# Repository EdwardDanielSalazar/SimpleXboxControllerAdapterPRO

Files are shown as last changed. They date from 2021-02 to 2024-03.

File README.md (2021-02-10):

# Simple Xbox Controller Adapter

## Functionality

Following the instructions below and using the [latest release](https://github.com/jimnarey/SimpleXboxControllerAdapter/releases) of this project you can create a simple Arduino-based adapter to use Xbox 360, Xbox One, PS3 and PS4 controllers with an original Xbox console.

## Background

This is an adaptation/fork of Ryzee119's excellent [four-way wired/wireless controller adapter](https://github.com/Ryzee119/ogx360/) to allow the use of Xbox One and Xbox 360 controllers (wired and wireless) on an original Xbox console. 

The objectives of this project were:
* A simple hardware build, using only off-the-shelf parts (at present, an Arduino Leonardo paired with a generic USB Host Shield). 
* Simple soldering. *A no solder version is possible if using the right choice of USB Host Shield*. 
* Reduced, simpler code to make playing around with it as straightforward as possible.
* Reduced functionality, reflecting the simpler code. Only wired controllers are supported and Steel Battalion emulation is not. 
* Support for additional controllers (so far, PS3 & PS4 controller support has been added).
* To provide full, foolproof instructions to enable anyone who's broadly comfortable with an Arduino to make an adapter and anyone who is broadly comfortable with the command line and IDEs to edit and build the code. So this document is a key part of the project.

This started when I dusted off my old Xbox and wanted to make something to use newer controllers with it. There's plenty of previous work on this and as I develop this document I'll link to more and more of it, but even with some experience of AVR and PIC programming it was a bit of a slog working out how to do it. The two biggest barriers were the complexity of some of the projects out there and/or getting them to build using reliable, free/open-source tools.

A significant factor in basing this project on ogx360 rather than XBOXPadMicro/XInput (see below) was that it was possible to clone, edit, and build without too much fighting with tools/IDE(s). The ogx360 project was originally built in Atmel/Microchip Studio which is Windows only (I could have lived with this) but it kept causing my mouse pointer to stall every 60 seconds (I really couldn't) because it apparently [fears some USB mice](https://www.avrfreaks.net/forum/mouse-pointer-stutters-when-connecting-usb-devices-while-running). This project started out with VSCode.

Even better, ogx360 has been transitioned to Platform IO and this project has followed suit. The old VSCode/CMake tools branch can be found at cmake_master and was used up to release 1.2.

Another important factor was starting with something which included the Xbox console's vendor-specific challenge/response values (see 'Alternatives & other projects to look at' below for more on this).

### Status

Release 1.3 differs from ogx360 as follows:
* Support for Xbox One and Xbox 360 *wireless* controllers has been removed.
* Support for multiple controllers has been removed. It supports a single controller connected via USB.
* Steel Battalion support has been removed, resulting in a smaller binary (and space for more controllers to be supported).
* PS3 controller support (via USB) has been added. 
* PS4 controller support (via USB) has been added. 
* Basic motion controls, using PS3/4 controllers is implemented.
* Motion controls can be enabled/disabled (PS + R2)
* Motion control sensitivity can be set (PS + R1) - crude, and definitely beta.
* The code supports an OLED screen displaying rumble/motion status.
* Replacement STL files for 3D printing a case have been added. For now, these assume use of an OLED screen. A non-OLED case to follow.
* The non-OLED release isn't properly tested. Consider beta for now.

### Future Work

These are broadly the priorities for now, not necessarily in order:
* Add instructions for building with an Arduino Pro Micro and mini USB Host Shield. This won't be a no-solder option but will be more compact. Thanks to Phantom8 for some really useful help with this already.
* Improving this document. The current build instructions rely on using VS Code (a command line only option will follow) and don't fully cover MacOS or cover Windows at all.
* Adding some scripts to make flashing the binary easier.

The OLED version currently uses 98% of the Leonardo's flash so it won't be possible to add further controllers without removing something else. Since removing the OLED only frees up about 9% of the flash, changes to the code will probably be limited to bug fixes and minor improvements, e.g. to the motion sensitivity options. I'm beginning to look at other microcontrollers to provide for significant additional functionality.

## Making One

For now, these instructions cover using a 'full size' Arduino Leonardo and USB Host Shield. You could get it working with an Arduino Micro, Pro Micro (set to run on 5V at 16Mhz) with a little adaptation and I'll add instructions for this in due course. Using a Leonardo is the simplest way, however.

### You will need

* An Arduino Leonardo/clone. Make sure it has the ICSP pin header (the separate, 6 pin header in the rear/centre). All those I could see on a quick skim of Amazon and eBay seemed to have one but I've seen references online to clones which do not.

Arduino Leonardo with ICSP header highlighted

* A standard size USB Host Shield (i.e. not one designed for a Pro Micro/Mini). Again, make sure this has the ICSP socket/header on the underside:

Underside of host shield with ICSP header/plug

* If you'd prefer to avoid soldering altogether, also ensure your choice of shield comes with the power supply pads pre-soldered. Mine, made by ARCELI, did not but it's the work of minutes if you're comfortable with soldering iron. Amazon (in the UK, at least) has an unbranded alternative (for about twice the price!) with the pads pre-soldered. These are the three pads:

Arduino USB host shield with power supply pads highlighted

* A USB-A female to Xbox Controller male/plug adapter. These are a few £/$ on eBay and [a better choice than hacking apart an Xbox peripheral](https://xboxdevwiki.net/Xbox_Input_Devices#USB_Adapters)
* A total of two micro USB cables. Most Leonardos come with one.

## For the OLED Version

* One SSD1306-based 128x32 OLED screen. These are available cheaply on Amazon or eBay.
* Four wires (<10cm 4 way ribbon cable is ideal).
* (Optional) A four way (or equivalent, e.g. 4 x 1 way) dupont connector. Alternatively the wires can be soldered onto the OLED direct.
* (Optional) heatshrink.
* (Optional) Another Arduino (Uno/Leonardo/Micro/Pro Micro) and some male to female jumper wires to re-flash the bootloader onto the Leonardo if something goes wrong when using Avrdude. If you follow the instructions and - in particular - are very careful to (re-)produce the Avrdude command correctly, it won't. You could of course use a dedicated AVR hardware programmer for this if you have one.

### Hardware build

* Check whether the pads need soldering on your USB Host Shield using the image above.
* If they're not, [this](https://learn.sparkfun.com/tutorials/how-to-work-with-jumper-pads-and-pcb-traces/all) is a decent tutorial on soldering jumper pads though there are several on YouTube which may be better if you're not confident with a soldering iron.
* Plug the USB Host Shield into the Leonardo.
* If you're not adding an OLED, you're done.

## Adding an OLED

* Proper instructions to follow. In short, the wires need to be soldered to the underside of the Leonardo and then soldered/connected using a dupont connector to the OLED.

### Flashing the firmware

Notes:
* This section covers the process for Ubuntu/Debian and will be expanded with more detail and MacOS instructions soon. I'll get round to Windows eventually but for now the process is well explained in [one of the ogx360 readmes](https://github.com/Ryzee119/ogx360/tree/master/Firmware).
* The flash script under /Firmware was written for my own convenience and may need adapting to your own setup - don't run it without checking! Use the method below.

We need to use Avrdude for this, rather than the Arduino IDE. Generally when you flash code onto an Arduino with the IDE it appears to a connected host (e.g. a PC) as a serial device, as this is a feature of the pre-flashed bootloader. Some Leonardos come with a version of the bootloader which makes it appear as a keyboard/mouse device and there are plenty of Leonardo-based projects which make use of this. In any case, neither of these is what we need and the Arduino IDE can't help us.

No special hardware (e.g. a programmer) is needed.

* Open two terminal windows/panes
* In one command prompt type ```sudo apt-get update && sudo apt-get install avrdude```
* Get the [latest version of the binary](https://github.com/jimnarey/SimpleXboxControllerAdapter/releases) (sxbca.bin)
* In one terminal type in ```dmesg -wH```
* Plug in the Leonardo via USB and you should see some dmesg output about it. If the Leonardo has the standard bootloader installed it will appear as a composite keyboard and mouse. If it has the alternative Caterina bootloader installed it will appear as an Arduino device. It doesn't matter which.
* Note the serial port the Arduino is connected to. In my case it's always /dev/ttyACM0
* In the second terminal window, navigate to where the sxbca.bin file is stored and - *without pressing Enter* - type in the following line, changing the name of the serial port if needed: 
```
avrdude -p atmega32u4 -P /dev/ttyACM0 -c avr109 -U flash:w:sxbca.bin -C /etc/avrdude.conf'
```
* Press the reset button on the Leonardo and *when you see the dmesg output register a new USB device* hit 'Enter'. Avrdude will then flash the firmware. You should have eight seconds from pressing the reset button before the Arduino reverts to its normal state. When this happens, you'll see it again in dmesg. You can just press the reset button again if this happens.
* All done. Plug an Xbox One/360/PS3/PS4 controller into the USB Host Shield and the Leonardo into the Xbox console and everything should work.

Note - the correct command for MacOS is probably the following but this will be tested/confirmed soon.
```
avrdude -p atmega32u4 -P /dev/ttyACM0 -c avr109 -U flash:w:sxbca.bin -C /usr/local/Cellar/avrdude/6.3_1/etc/avrdude.conf'
```

### Using One

* For the most part, just plug the device into the Xbox via the micro-USB port and the controller into the device via the USB-A port.
* Holding XBOX/PS+L2 enables rumble, unless you've compiled a version which doesn't support it by amending the relevant line in settings.h. You know if you've done this.
* If you're using rumble, plug the device into a wall PSU which supplies 7V-12V using the Leonardo's power socket. If you don't, then it will likely freeze when rumble takes place as the power draw is too high.
* If you remove external power while using the device with a PS controller, press the reset button. During my testing so far the PS controllers are clever enough not to start charging themselves if there is no external power (the voltage on USB VCC can drop below 4V with a PS controller connected). However, they don't always stop charging if external power is removed and this will stress the device.
* Holding PS+R2 enables/disables motion controls. Tip the controller forward to mimic right stick up, back to mimic right stick down. Roll the controller to mimic right stick right, roll left for right stick left. There are improvements to be made here but it works reasonably well.
* Holding PS+R1 sets the sensivity of the motion controls but the effect is, for the time being, subtle. What's happening is the device changes the angle of the controller (in any direction) which it considers to be equivalent to pressing the stick fully in the respective direction. High sensivity = 30deg, medium=45deg, low=60deg. It's not great and what I really need to do here is apply a curve to the input.
* Motion controls and the right stick can be used at the same time.
* With no feedback from the software this is never going to be like playing Splatoon, but I do intend to get it to the point where it's a sneaky way of lining up headshots in Halo.

### Reflashing the standard Arduino bootloader

If you want to get the Leonardo back to its stock state for whatever reason, just follow the same process as above but point Avrdude to the bootloader file which comes with the Arduino IDE. Where this is will depend on where the Arduino IDE is installed. Within the Arduino IDE folder on my (Ubuntu) system it was here:

```
XXXXX/arduino-1.8.12/hardware/arduino/avr/bootloaders/caterina/Leonardo-prod-firmware-2012-12-10.hex
```

My Arduino IDE folder contains an older version of the firmware (Leonardo-prod-firmware-2012-04-26.hex) - I'm not sure what the difference is. It also contains an alternative firmware - Caterina-Leonardo.hex - which when loaded on the Arduino makes it appear as an Arduino device rather than a keyboard/mouse.

This time, when you first plug the Arduino in it will appear in the dmesg output as a gamepad device. When you press the reset button it will appear again as an Arduino device.

## What to do if something goes wrong

Something 'going wrong' could mean:

* You time the flashing incorrectly, when the Leonardo is not in the right mode (achieved by pressing reset). However, I have done this accidentally and it's been fine. Several tutorials elsewhere warn about this however.
* You made a typo in the Avrdude command. E.g. Avrdude erases the flash before looking for the hex/bin file you point it towards. So if you make a typo in 'sxbca.bin' it will cheerfully erase your Arduino and leave it at that. It's hard to imagine anyone being daft enough to do this and then getting into a mild panic when they connect the device to the Xbox, it doesn't work, and they assume it's a consequence of refactoring code at 3am but it could happen...

In these and other cases you won't be able to flash the firmware properly with Avrdude (it either doesn't run, or does run but the device doesn't work). You also won't be able to load sketches with the Arduino IDE. You'll therefore need either another Arduino to use as an ISP (In System Programmer) or a hardware programmer. If you own a hardware programmer you probably don't need any help with this.

### Reflashing the Leonardo with another Arduino configured as an ISP

You can use either an Uno or any Arduino based on the atmega32u4 (Leonardo, Micro, Pro Micro - probably others). [This page](https://www.arduino.cc/en/Tutorial/BuiltInExamples/ArduinoISP) has a comprehensive explantion of how to do this. *Although I refer below to soldering an ISP, you can make one perfecly well with jumper leads*

Recognising the likelihood that I'd screw up the flashing process at some point, before I started this project I soldered together a permanent ISP based on an Arduino Pro Micro clone, based on the instructions [here](https://www.instructables.com/Mini-Breadboard-Pro-Micro-ISP-for-DIP8-ATTiny-Seri/) (these actually cover doing it with a breadboard but the principles are the same).

The main takeaway from this tutorial is that when using a Pro Micro rather than an Uno you need to change the value of the RESET pin in the ISP sketch. Otherwise it's the pretty much the same. If you plan to play around with the code in this project or related ones (see below) making a permanent ISP is well worth doing. Using a Pro Micro and by soldering the LED resistors to the LED legs you can make something very compact:

Arduino Pro Micro ISP

## Alternatives & other projects to look at

* [Ryzee119's ogx360 project](https://github.com/Ryzee119/ogx360/), on which this is based.
    * Uses up to four Arduino Pro Micros to provide up to four emulated original Xbox controllers, connected via a custom PCB to a MAX3421 USB Host Controller IC (the same IC used in Arduino USB Host Shields).
    * Unfortunately, the MAX3421 is not (to the very best of my knowledge) available in a through-hole package making it tough work for a hobby project. Some people laugh in the face of surface mount soldering; I am not amongst them.
    * *Note:* You can actually flash the [ogx360 master binary](https://github.com/Ryzee119/ogx360/releases) to a Leonardo/Pro Micro following the instructions above and it just works with a wired controller. This doesn't seem to be documented in the otherwise comprehensive readmes. As this firmware has rumble enabled you may well find it hangs the device when rumble is activated for any length of time if you apply it to this hardware build rather than Ryzee119's.
* [Another Ryzee199 project](https://github.com/Ryzee119/ogx360_t4) pretty much meets the aims of this one (simple, no soldering, other controller support) but relies on the [Teensy 4.1](https://www.pjrc.com/store/teensy41.html). This works with the Arduino IDE, PlatformIO etc but is a more expensive option, reflecting the fact the board has an integral USB host, SD card, ethernet support etc. and a 32bit processor. But very straightforward.
* [The XBOXPadMicro project](https://github.com/bootsector/XBOXPadMicro) allows for a customised controller to be built to work with a classic Xbox Console, using an Arduino's digital input pins. 
    * Doesn't include any USB host functionality, so you can't plug another controller into it. It has everything you need to build/adapt a custom controller, however. I plan to use this to get a [TAC-2](https://en.wikipedia.org/wiki/TAC-2) working with PC/Xbox. Nobody needs more than one button, as the Amiga port of Street Fighter 2 demonstrated...
    * It's written in C and would need some work to adapt it for use with the broader Arduino ecosystem, allowing it to be adapted for use with USB controllers.
* [The Arduino XInput library](https://github.com/dmadison/ArduinoXInput) has everything needed to build a project to make an Arduino appear as an Xinput controller (the protocol used by the Xbox, successor consoles and Windows) except the vendor-specific HID challenge/response code needed to work with an actual Xbox console. So it will work with Windows/Linux/Mac but not the console itself.
* This project and both of Ryzee119's use the [Arduino USB Host Shield Library](https://github.com/felis/USB_Host_Shield_2.0) to handle communication between the device and the Xbox One/360 controller. The speed with which you can pick up an Arduino, a shield and have a PS4/Xbox One/360/etc. controller talking to Linux/Windows/Mac via serial is really impressive. It's well supported and has support for a wide range of USB controllers, including great example sketches.

# Development/Building the Binary

This covers MacOS/Linux (Ubuntu). Some of it holds for Windows (VSCode, Platform IO) but the instructions for installing and using Avrdude differ. More to follow.

## Install Command Line Tools

### Linux (Ubuntu, Debian etc)

* From a command prompt run: 
```
sudo apt-get install avrdude git
```

### MacOS
* From a command prompt run:
```
xcode-select --install
brew tap osx-cross/avr
brew install avrdude
```
## Install VS Code (Mac OS & Linux)

* Download and install Visual Studio Code here: https://code.visualstudio.com/download
* Open VS Code, click on the 'extensions' icon on the left hand side and install 'Platform IO. Open and close VS Code to finalise install.
* Clone this project to an appropriate location with 'git clone https://github.com/jimnarey/SimpleXboxControllerAdapter'
* Access the Platform IO home tab by clicking the (very small) Platform IO icon on the bottom bar of the VS Code window.
* Select 'Open Project' and point the folder selection window at the cloned repo.

## Build

* Click the tick icon in the bottom bar of the VS Code window.
* Clicking the arrow button, to upload the code, doesn't work without a bit of further config. I need to do a bit of digging into this but for now use Avrdude, which is how the original CMake version of this project was flashed and is more robust.

## Develop/Extend

When adding PS3 controller support I used the Leonardo's second UART/Serial port ('Serial1' in the Arduino library) for debugging. This can be accessed on pins 20 and 21. You'll need an inexpensive USB to serial module to connect it to a PC/Mac. You can then open the Arduino IDE, point it to the correct serial port (in my case /dev/ttyUSB0) and start the Serial Monitor. On Ubuntu (at least) using 'screen' is more convenient - install with ```sudo apt-get install screen```.

The lines for initialising Serial1 are in main.cpp and commented out in most commits. Assuming you uncomment these and don't change the baud from 9600, you'd then start screen with the following, amending the name of the serial port if necessary:

```
screen /dev/ttyUSB0 9600
```

There is almost no space left on the ATmega32u4's flash with the current build so it may be necessary to remove support for one or more controllers in order to add in support for others.

### Steps for adding additional controllers

Adding PS3 and PS4 controller support involved the following:
* Adding an #include for the PS3USB/PS4USB library
* Instantiating the PS3USB/PS4USB class using the same format as the existing Xbox controller classes (pass it a pointer to the 'USBHost' object)
* Adding a check for whether a PS3/PS4 controller is connected to controllerConnected()
* Reproducing the calls to the two Xbox controller classes in getButtonPress() and getAnalogHat()
* When only some buttons worked, using the output from Serial1 (via the USB to serial module) to see what was coming back from the controller by adding temporary code to the main loop, e.g.
```
if (PS3Wired.PS3Connected) {
    Serial1.println(PS3Wired.getButtonPress(R2));
}
```
* Adding lines like this for one button at a time makes it much easier to make sense of the serial output
* Making necessary changes to the values returned from the controller. For example, the Xbox expects a value from each axis on each analog stick between -32768 and 32767 - so a signed 16bit int. The PS3 and PS4 controller each provides an unsigned 8bit int instead: 0 - 255. The lines of code which deal with this are commented. The face buttons also needed remapping to their physical counterparts on the Xbox controller.

Thanks to Ryzee119 for helping resolve some (to me) incomprehensible linker errors when trying to import the PS4 library for the first time.

I have since tested importing and instantiating the classes for Bluetooth, Wii controllers and general HID controllers so making use of these should be possible without any additional dependencies being used. However, all of these together with the current functionality resulted in a 43K binary, so they can't all be used together.

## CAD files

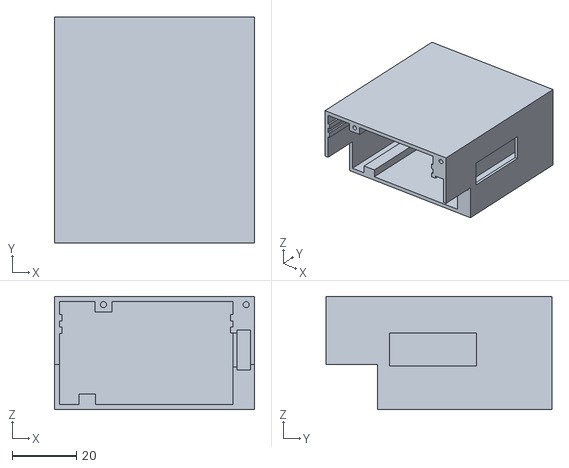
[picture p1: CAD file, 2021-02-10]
Case/Main Case - OLED.STL
62.1 x 70.2 x 35.2

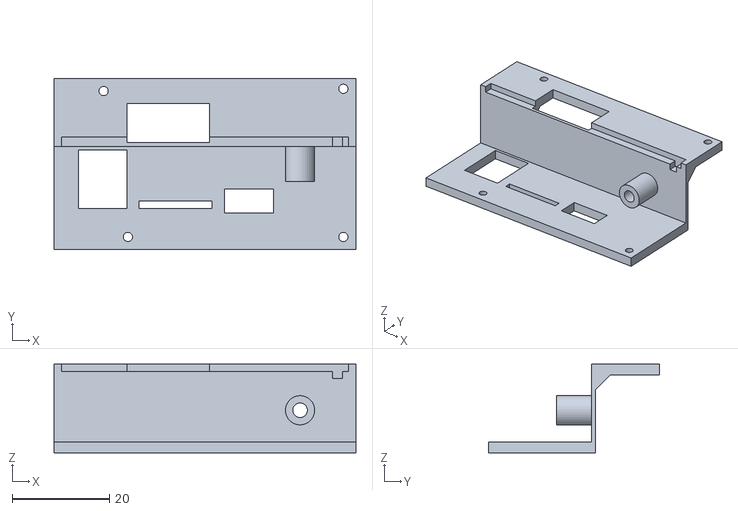
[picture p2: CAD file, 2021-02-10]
Case/Front cover - OLED.STL
62.1 x 35.2 x 18.3

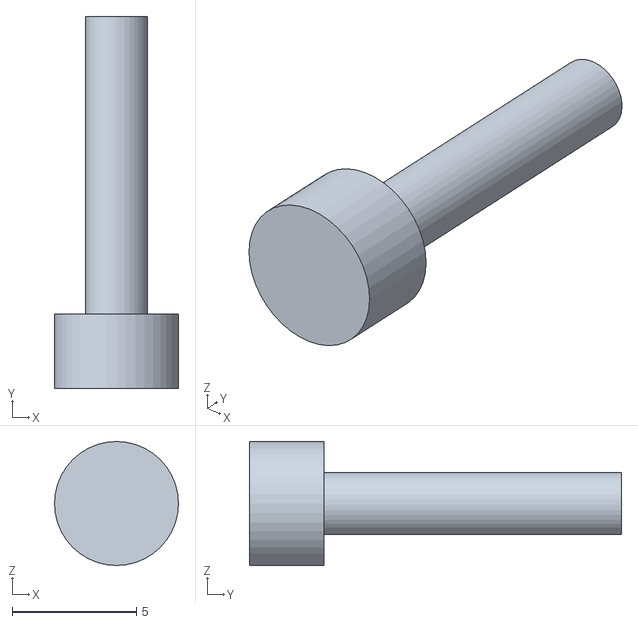
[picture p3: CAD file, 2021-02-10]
Case/Reset button shaft_12mm.STL
5.00 x 15.0 x 5.00

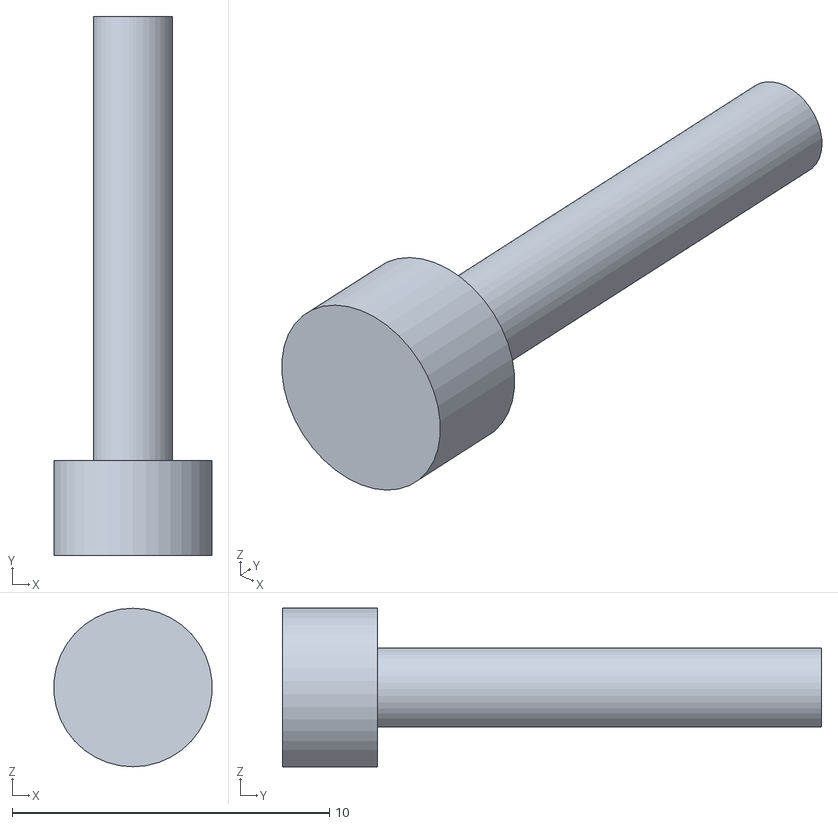
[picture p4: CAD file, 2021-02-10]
Case/Reset button shaft_14mm.STL
4.98 x 17.0 x 5.00

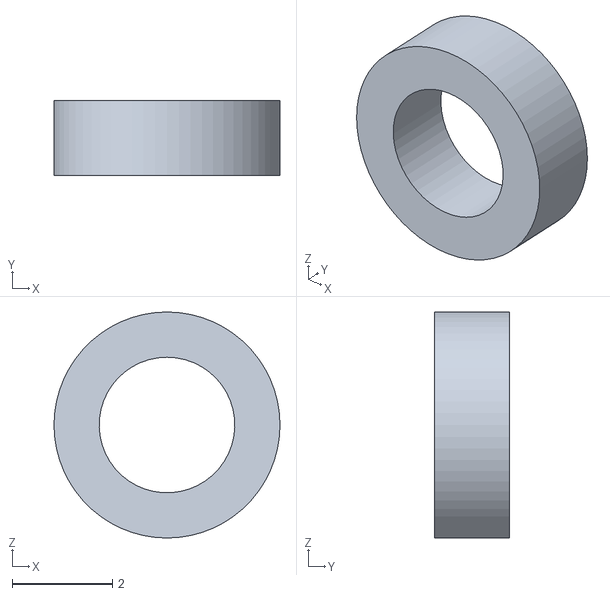
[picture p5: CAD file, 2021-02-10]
Case/Reset button base.STL
4.50 x 1.50 x 4.50

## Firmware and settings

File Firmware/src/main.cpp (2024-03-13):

#include "settings.h"
#include "xiddevice.h"
// #include "EEPROM.h" // ?? Remove this ??
#include <SPI.h>

#ifdef ENABLE_XBOX360
#include <XBOXRECV.h>
#endif
#ifdef ENABLE_XBOXBT
#include <XBOXONESBT.h>
#endif

//#include <PS3USB.h>
#ifdef ENABLE_PS4BT
#include <PS4BT.h>
#endif
#ifdef ENABLE_XBOXONEUSB
#include <XBOXONE.h>
#endif
#ifdef ENABLE_SWITCHBT
#include <SwitchProBT.h>
#endif


//playerID is set in the main program based on the slot the Arduino is installed.
// uint8_t playerID;
//Xbox gamepad data structure to store all button and actuator states for all four controllers.
USB_XboxGamepad_Data_t XboxOGDuke;
//Default XID device to emulate
uint8_t ConnectedXID = DUKE_CONTROLLER;
//Flag is set when the device has been successfully setup by the OG Xbox
bool enumerationComplete = false;
//Timer used to time disconnection between SB and Duke controller swapover
uint32_t disconnectTimer = 0;

USB Usb;


#ifdef ENABLE_PS4BT
BTD Btd(&Usb);
PS4BT PS4Wired(&Btd, PAIR);
#endif
#ifdef ENABLE_SWITCHBT
BTD Btd(&Usb);
SwitchProBT SwitchPro(&Btd, PAIR);
#endif
#ifdef ENABLE_XBOXONEUSB
XBOXONE XBOXONE(&Usb);
#endif
uint8_t getButtonPress(ButtonEnum b);
int16_t getAnalogHat(AnalogHatEnum a);
void setRumbleOn(uint8_t lValue, uint8_t rValue);
void setLedOn(LEDEnum led); // TO DO - do something with this
uint8_t controllerConnected();
void checkControllerChange();

void getStatus();

//XBOXONE XboxOneWired(&UsbHost);

#ifdef ENABLE_XBOX360
XBOXRECV Xbox360Wired(&Usb);
#endif
#ifdef ENABLE_XBOXBT
BTD Btd1(&Usb);
XBOXONESBT Xbox(&Btd1, PAIR);
#endif
//PS3USB PS3Wired(&UsbHost); //defines EP_MAXPKTSIZE = 64. The change causes a compiler warning but doesn't seem to affect operation

uint8_t controllerType = 0;
uint8_t status = 0;

#ifdef ENABLE_RUMBLE
bool rumbleOn = true;
#endif

int main(void)
{
    //Init the Arduino Library
    init();
    //Init IO
    pinMode(USB_HOST_RESET_PIN, OUTPUT);
    pinMode(ARDUINO_LED_PIN, OUTPUT);
    digitalWrite(USB_HOST_RESET_PIN, LOW);
    digitalWrite(ARDUINO_LED_PIN, HIGH);

    //Init the LUFA USB Device Library
    SetupHardware();
    GlobalInterruptEnable();

    // Initialise the Serial Port
     //Serial1.begin(115200);

    //Init the XboxOG data arrays to zero.
    memset(&XboxOGDuke, 0x00, sizeof(USB_XboxGamepad_Data_t));

    digitalWrite(USB_HOST_RESET_PIN, LOW);
    delay(20); //wait 20ms to reset the IC. Reseting at startup improves reliability in my experience.
    digitalWrite(USB_HOST_RESET_PIN, HIGH);
    delay(20); //Settle
    while (Usb.Init() == -1)
    {
        //while (1); // Halt
        digitalWrite(ARDUINO_LED_PIN, !digitalRead(ARDUINO_LED_PIN));
       // delay(500);
     
    }
     
    while (1)
    {
        Usb.busprobe();
        Usb.Task();

        checkControllerChange();
       
        if (controllerType)
        {
            //Read Digital Buttons
            XboxOGDuke.dButtons=0x0000;
            if (getButtonPress(UP))      XboxOGDuke.dButtons |= DUP;
            if (getButtonPress(DOWN))    XboxOGDuke.dButtons |= DDOWN;
            if (getButtonPress(LEFT))    XboxOGDuke.dButtons |= DLEFT;
            if (getButtonPress(RIGHT))   XboxOGDuke.dButtons |= DRIGHT;;
            if (getButtonPress(START))   XboxOGDuke.dButtons |= START_BTN;
            if (getButtonPress(BACK))    XboxOGDuke.dButtons |= BACK_BTN;
            if (getButtonPress(L3))      XboxOGDuke.dButtons |= LS_BTN;
            if (getButtonPress(R3))      XboxOGDuke.dButtons |= RS_BTN;

            //Read Analog Buttons - have to be converted to digital because x360 controllers don't have analog buttons
            getButtonPress(A)    ? XboxOGDuke.A = 0xFF      : XboxOGDuke.A = 0x00;
            getButtonPress(B)    ? XboxOGDuke.B = 0xFF      : XboxOGDuke.B = 0x00;
            getButtonPress(X)    ? XboxOGDuke.X = 0xFF      : XboxOGDuke.X = 0x00;
            getButtonPress(Y)    ? XboxOGDuke.Y = 0xFF      : XboxOGDuke.Y = 0x00;
            getButtonPress(L1)   ? XboxOGDuke.WHITE = 0xFF  : XboxOGDuke.WHITE = 0x00;
            getButtonPress(R1)   ? XboxOGDuke.BLACK = 0xFF  : XboxOGDuke.BLACK = 0x00;
            
            //Read Analog triggers
            if ((controllerType) == 1||(controllerType) == 2||(controllerType) == 4||(controllerType) == 5){
            XboxOGDuke.L = getButtonPress(L2); //0x00 to 0xFF
            XboxOGDuke.R = getButtonPress(R2);
            }
            
            if ((controllerType) == 3){
            XboxOGDuke.L = getButtonPress(ZLl); //0x00 to 0xFF
            XboxOGDuke.R = getButtonPress(ZR);
            }
            
             //0x00 to 0xFF
            //Read Control Sticks (16bit signed short)
            XboxOGDuke.leftStickX = getAnalogHat(LeftHatX);
            XboxOGDuke.leftStickY = getAnalogHat(LeftHatY);
            XboxOGDuke.rightStickX = getAnalogHat(RightHatX);
            XboxOGDuke.rightStickY = getAnalogHat(RightHatY);
                      
            //Anything that sends a command to the Xbox 360 controllers happens here.
            //(i.e rumble, LED changes, controller off command)
            static uint32_t commandTimer = 0;
            static uint32_t xboxHoldTimer = 0;
            static uint32_t timenow = 0;
            static uint32_t frecuency = 1000;
            static uint32_t state;
            if (millis() - commandTimer > 16)
            {
                // Enable motion controls
                // TO DO - only turn on motion when compatible controller connected
                                
                // Enable rumble
                if (getButtonPress(XBOX) && getButtonPress(L2) > 0x00)
                {
                    if (xboxHoldTimer == 0)
                    {
                        xboxHoldTimer = millis();
                    }
                    if ((millis() - xboxHoldTimer) > 1000 && (millis() - xboxHoldTimer) < 1100)
                    {
                        xboxHoldTimer = 0;
                        #ifdef ENABLE_RUMBLE
                        rumbleOn = !rumbleOn;
                        #endif
                    }
                }
                if ((controllerType) == 3){
                if (getButtonPress(HOME) && getButtonPress(ZLl) > 0x00)
                {
                    if (xboxHoldTimer == 0)
                    {
                        xboxHoldTimer = millis();
                    }
                    if ((millis() - xboxHoldTimer) > 1000)
                    {
                        xboxHoldTimer = 0;
                        if(millis()-timenow >= frecuency){
                            state=!state;
                       #ifdef ENABLE_SWITCHBT
                        if(state==1){
                            SwitchPro.setLedHomeOff();
                        }else{
                            SwitchPro.setLedHomeOn();
                        } 
                        #endif
                         timenow = millis();                        
                        }
                        #ifdef ENABLE_RUMBLE
                        
                        rumbleOn = !rumbleOn;
                        #endif
                        
                    }
                }
                }
                #ifdef ENABLE_RUMBLE
                //START+BACK TRIGGERS is a standard soft reset command.
                //We turn off the rumble motors here to prevent them getting locked on
                //if you happen to press this reset combo mid rumble.
                else if (getButtonPress(START) && getButtonPress(BACK) &&
                            getButtonPress(L2) > 0x00 && getButtonPress(R2) > 0x00)
                {       
                    //Turn off rumble
                    XboxOGDuke.left_actuator = 0;
                    XboxOGDuke.right_actuator = 0;
                    XboxOGDuke.rumbleUpdate = 1;
                    
                }
                #endif
                else
                {   
                    xboxHoldTimer = 0; //Reset the XBOX button hold time counter.
                    #ifdef ENABLE_RUMBLE 
                    if (XboxOGDuke.rumbleUpdate == 1)
                    {   
                        setRumbleOn(XboxOGDuke.left_actuator, XboxOGDuke.right_actuator);
                        XboxOGDuke.rumbleUpdate = 0;
                    }
                    #endif
                }
                commandTimer = millis();
            }

            sendControllerHIDReport();
        }
        //Handle Player 1 controller connect/disconnect events.
        if (controllerConnected() && disconnectTimer == 0)
        {
            USB_Attach();
            if (enumerationComplete)
            {
                digitalWrite(ARDUINO_LED_PIN, LOW);
            }
        }
        else if (millis() > 7000)
        {
            digitalWrite(ARDUINO_LED_PIN, HIGH);
            USB_Detach(); //Disconnect from the OG Xbox port.
        }
        else
        {
            USB_Attach();
            sendControllerHIDReport();
        }


        //THPS 2X is the only game I know that sends rumble commands to the USB OUT pipe
        //instead of the control pipe. So unfortunately need to manually read the out pipe
        //and update rumble values as needed!
         uint8_t ep = Endpoint_GetCurrentEndpoint();
         static uint8_t report[6];
         Endpoint_SelectEndpoint(0x02); //0x02 is the out endpoint address for the Duke Controller
         if (Endpoint_IsOUTReceived())
         {
             Endpoint_Read_Stream_LE(report, 6, NULL);
             Endpoint_ClearOUT();
             if (report[1] == 0x06)
        
                 {
                XboxOGDuke.left_actuator = report[3];
                XboxOGDuke.right_actuator = report[5];
                XboxOGDuke.rumbleUpdate = 1;
            }
            report[1] = 0x00;
        }
        Endpoint_SelectEndpoint(ep); //set back to the old endpoint.

    }
}

/* Send the HID report to the OG Xbox */
void sendControllerHIDReport()
{
    if (USB_Device_GetFrameNumber() - DukeController_HID_Interface.State.PrevFrameNum >= 4)
    {
        HID_Device_USBTask(&DukeController_HID_Interface); //Send OG Xbox HID Report
    }
    USB_USBTask();
}

// TO DO - remove the separate controller connected checks in these functions
//Parse button presses for each type of controller
uint8_t getButtonPress(ButtonEnum b)
{
    
    uint8_t psVal = 0;
    
    #ifdef ENABLE_XBOX360
    if (Xbox360Wired.XboxReceiverConnected){
        return Xbox360Wired.getButtonPress(b);
    }
    #endif
    #ifdef ENABLE_XBOXBT
    if (Xbox.connected())
    {
        if (b == L2 || b == R2)
        {
            //Xbone one triggers are 10-bit, remove 2LSBs so its 8bit like OG Xbox
            return (uint8_t)(Xbox.getAnalogButton(b) >> 2); 
        }
        else
        {
            return (uint8_t)Xbox.getButtonPress(b);
        }
    }
    #endif
    #ifdef ENABLE_XBOXONEUSB
    if (XBOXONE.XboxOneConnected)
    {
        if (b == L2 || b == R2)
        {
            //Xbone one triggers are 10-bit, remove 2LSBs so its 8bit like OG Xbox
            return (uint8_t)(XBOXONE.getButtonPress(b) >> 2); 
        }
        else
        {
            return (uint8_t)XBOXONE.getButtonPress(b);
        }
    }
    #endif
    

    #ifdef ENABLE_SWITCHBT
    if (SwitchPro.connected())
    {            
           switch (b) {
			// Remap the PS4 controller face buttons to their Xbox counterparts
			case A:
				psVal = (uint8_t)SwitchPro.getButtonPress(B);
				break;
			case B:
				psVal = (uint8_t)SwitchPro.getButtonPress(A);
				break;
			case X:
				psVal = (uint8_t)SwitchPro.getButtonPress(Y);
				break;
			case Y:
				psVal = (uint8_t)SwitchPro.getButtonPress(X);
				break;
            case BACK:
				psVal = (uint8_t)SwitchPro.getButtonPress(MINUS);
				break;
            case R3:
				psVal = (uint8_t)SwitchPro.getButtonPress(R3);
				break;  
            case L3:
				psVal = (uint8_t)SwitchPro.getButtonPress(L3);
				break; 
            case START:
				psVal = (uint8_t)SwitchPro.getButtonPress(PLUS);
				break;  
            case UP:
				psVal = (uint8_t)SwitchPro.getButtonPress(UP);
				break; 
            case DOWN:
				psVal = (uint8_t)SwitchPro.getButtonPress(DOWN);
				break; 
            case LEFT:
				psVal = (uint8_t)SwitchPro.getButtonPress(LEFT);
				break; 
            case RIGHT:
				psVal = (uint8_t)SwitchPro.getButtonPress(RIGHT);
				break; 
            case R1:
				psVal = (uint8_t)SwitchPro.getButtonPress(R);
				break; 
            case L1:
				psVal = (uint8_t)SwitchPro.getButtonPress(L);
				break;
                  
            case ZLl:
				if(SwitchPro.getButtonPress(ZLl)){
                psVal = 0xff;
                }else{
                psVal = 0x00;
                }
              	break; 
            case ZR:
				if(SwitchPro.getButtonPress(ZR)){
                psVal = 0xff;
                }else{
                psVal = 0x00;
                }
				break;          
                        
			// Call a different function from the PS4USB library to get the level of
			// pressure applied to the L2 and R2 triggers, not just 'on' or 'off
			default:
				psVal = (uint8_t)SwitchPro.getButtonPress(b);
		}
		return psVal;
    }
    #endif
    
	#ifdef ENABLE_PS4BT
    if (PS4Wired.connected()) {
		switch (b) {
			// Remap the PS4 controller face buttons to their Xbox counterparts
			case A:
				psVal = (uint8_t)PS4Wired.getButtonPress(CROSS);
				break;
			case B:
				psVal = (uint8_t)PS4Wired.getButtonPress(CIRCLE);
				break;
			case X:
				psVal = (uint8_t)PS4Wired.getButtonPress(SQUARE);
				break;
			case Y:
				psVal = (uint8_t)PS4Wired.getButtonPress(TRIANGLE);
				break;
			// Call a different function from the PS4USB library to get the level of
			// pressure applied to the L2 and R2 triggers, not just 'on' or 'off
			case L2:
				psVal = (uint8_t)PS4Wired.getAnalogButton(L2);
				break;
			case R2:
				psVal = (uint8_t)PS4Wired.getAnalogButton(R2);
				break;
			default:
				psVal = (uint8_t)PS4Wired.getButtonPress(b);
		}
		return psVal;
	}
    #endif

    return 0;
}

//Parse analog stick requests for each type of controller.
int16_t getAnalogHat(AnalogHatEnum a)
{
#ifdef ENABLE_XBOX360
    if (Xbox360Wired.XboxReceiverConnected)
    {
        //int16_t val;
        //val = Xbox360Wired.getAnalogHat(a);
        //if (val == -32512) //8bitdo range fix
        //    val = -32768;
        return Xbox360Wired.getAnalogHat(a);
    }
    #endif
    #ifdef ENABLE_XBOXBT
        if (Xbox.connected())
        
         if (a == RightHatY || a == LeftHatY) {
			return (Xbox.getAnalogHat(a) + 0.5) * -1;
		    } else {
			return (Xbox.getAnalogHat(a));
		    }
    #endif
    #ifdef ENABLE_XBOXONEUSB
    if (XBOXONE.XboxOneConnected)
    return XBOXONE.getAnalogHat(a);
    #endif
    #ifdef ENABLE_SWITCHBT
   if (SwitchPro.connected()) {
        
		if (a == RightHatY || a == LeftHatY) {
			return (SwitchPro.getAnalogHat(a) - 127) * -19;
		} else {
			return (SwitchPro.getAnalogHat(a) - 129) * 20;
		}
    }
    #endif
    
	#ifdef ENABLE_PS4BT
    if (PS4Wired.connected()) {
		if (a == RightHatY || a == LeftHatY) {
			return (PS4Wired.getAnalogHat(a) - 127) * -255;
		} else {
			return (PS4Wired.getAnalogHat(a) - 127) * 255;
		}
	}
    #endif
    return 0;
}

#ifdef ENABLE_RUMBLE
//Parse rumble activation requests for each type of controller.
void setRumbleOn(uint8_t lValue, uint8_t rValue)
{
    if (rumbleOn) {
        #ifdef ENABLE_XBOX360
        if (Xbox360Wired.XboxReceiverConnected)
        {
           Xbox360Wired.setRumbleOn(lValue, rValue); 
        }
        #endif
        #ifdef ENABLE_XBOXBT
        if (Xbox.connected())
        {
            Xbox.setRumbleOn(lValue / 8, rValue / 8, lValue / 2, rValue / 2);
        }
        #endif
        #ifdef ENABLE_XBOXONEUSB
        if (XBOXONE.XboxOneConnected)
            XBOXONE.setRumbleOn(lValue / 8, rValue / 8, lValue / 2, rValue / 2);
        #endif
        #ifdef ENABLE_SWITCHBT
        if (SwitchPro.connected())
        {
            if (lValue == 0 && rValue == 0) {
            SwitchPro.setRumbleRight(false);
            SwitchPro.setRumbleLeft(false);
            } else {
            SwitchPro.setRumbleRight(true);
            SwitchPro.setRumbleLeft(true);
            }
        
        }
         #endif
         
        #ifdef ENABLE_PS4BT
        if (PS4Wired.connected())
        {   
            if (lValue == 0 && rValue == 0) {
                PS4Wired.setRumbleOff();
            } else {
                PS4Wired.setRumbleOn(RumbleLow);
            }
        }
        #endif
    }
}
#endif

//Parse LED activation requests for each type of controller.
void setLedOn(LEDEnum led)
{
    #ifdef ENABLE_XBOX360
    if (Xbox360Wired.XboxReceiverConnected)
        Xbox360Wired.setLedOn(led);  
    #endif
    
}


// TO DO - merge these two functions
uint8_t controllerConnected()
{
    uint8_t controllerType = 0;
    #ifdef ENABLE_XBOX360
    if (Xbox360Wired.XboxReceiverConnected)
       {
        controllerType =  1;
       }
    #endif
    #ifdef ENABLE_XBOXBT
    if (Xbox.connected())
       {
        controllerType =  2;
       }
    #endif
	#ifdef ENABLE_SWITCHBT
    if (SwitchPro.connected())
        controllerType =  3;
    #endif   
	#ifdef ENABLE_PS4BT
    if (PS4Wired.connected())
		controllerType =  4;
    #endif
    #ifdef ENABLE_XBOXONEUSB
    if (XBOXONE.XboxOneConnected)
		controllerType =  5;
    #endif

    return controllerType;
}

void checkControllerChange() {
    Usb.Task();
    uint8_t currentController = controllerConnected();
    if (currentController != controllerType) {
        controllerType = currentController;
    }
}

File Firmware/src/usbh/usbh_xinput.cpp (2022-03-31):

// Copyright 2021, Ryan Wendland, ogx360
// SPDX-License-Identifier: GPL-3.0-or-later

#include <usbhid.h>
#include "usbh_xinput.h"

//#define ENABLE_USBH_XINPUT_DEBUG
#ifdef ENABLE_USBH_XINPUT_DEBUG
#define USBH_XINPUT_DEBUG(a) Serial1.print(a)
#else
#define USBH_XINPUT_DEBUG(...)
#endif

//FIXME: This causes cast warnings.
#define GET_USHORT(a, b) *((uint16_t *)a[b])
#define GET_SHORT(a, b) *((int16_t *)a[b])
#define GET_UINT(a, b) *((uint32_t *)a[b])

static usbh_xinput_t xinput_devices[XINPUT_MAXGAMEPADS];
static uint8_t xdata[384];

#ifdef ENABLE_USBH_XINPUT_DEBUG
static void PrintHex8(uint8_t *data, uint8_t length) // prints 8-bit data in hex with leading zeroes
{
    char tmp[16];
    for (int i = 0; i < length; i++)
    {
        sprintf(tmp, "0x%.2X", data[i]);
        Serial1.print(tmp);
        Serial1.print(" ");
    }
    Serial1.print("\n");
}
#endif

usbh_xinput_t *XINPUT::alloc_xinput_device(uint8_t bAddress, uint8_t itf_num, EpInfo *in, EpInfo *out, xinput_type_t type)
{
    usbh_xinput_t *new_xinput = NULL;
    uint8_t index;
    for (index = 0; index < XINPUT_MAXGAMEPADS; index++)
    {
        if (xinput_devices[index].bAddress == 0)
        {
            new_xinput = &xinput_devices[index];
            USBH_XINPUT_DEBUG(F("USBH XINPUT: ALLOCATED NEW XINPUT\n"));
            break;
        }
    }

    if (new_xinput == NULL)
    {
        USBH_XINPUT_DEBUG(F("USBH XINPUT: COULD NOT ALLOCATE NEW XINPUT\n"));
        return NULL;
    }

    memset(new_xinput, 0, sizeof(usbh_xinput_t));
    new_xinput->bAddress = bAddress;
    new_xinput->itf_num = itf_num;
    new_xinput->type = type;
    new_xinput->usbh_inPipe = in;
    new_xinput->usbh_outPipe = out;
    new_xinput->led_requested = index + 1;
    new_xinput->chatpad_led_requested = CHATPAD_GREEN;

    if (new_xinput->type == XBOX360_WIRELESS)
    {
        WritePacket(new_xinput, xbox360w_controller_info, sizeof(xbox360w_controller_info), TRANSFER_PGM);
        WritePacket(new_xinput, xbox360w_unknown, sizeof(xbox360w_unknown), TRANSFER_PGM);
        WritePacket(new_xinput, xbox360w_rumble_enable, sizeof(xbox360w_rumble_enable), TRANSFER_PGM);
    }
    else if (new_xinput->type == XBOX360_WIRED)
    {
        uint8_t cmd[sizeof(xbox360_wired_led)];
        memcpy(cmd, xbox360_wired_led, sizeof(xbox360_wired_led));
        cmd[2] = index + 2;
        pUsb->outTransfer(bAddress, out->epAddr, sizeof(xbox360_wired_led), cmd);
    }
    else if (new_xinput->type == XBOXONE)
    {
        WritePacket(new_xinput, xboxone_start_input, sizeof(xboxone_start_input), TRANSFER_PGM);

        //Init packet for XBONE S/Elite controllers (return from bluetooth mode)
        if (VID == 0x045e && (PID == 0x02ea || PID == 0x0b00))
        {
            WritePacket(new_xinput, xboxone_s_init, sizeof(xboxone_s_init), TRANSFER_PGM);
        }

        //Required for PDP aftermarket controllers
        if (VID == 0x0e6f)
        {
            WritePacket(new_xinput, xboxone_pdp_init1, sizeof(xboxone_pdp_init1), TRANSFER_PGM);
            WritePacket(new_xinput, xboxone_pdp_init2, sizeof(xboxone_pdp_init2), TRANSFER_PGM);
            WritePacket(new_xinput, xboxone_pdp_init3, sizeof(xboxone_pdp_init3), TRANSFER_PGM);
        }
    }
    else if (new_xinput->type == XINPUT_MOUSE || new_xinput->type == XINPUT_KEYBOARD)
    {
        //Set to BOOT protocol
        pUsb->ctrlReq(bAddress,
                      0,                        //ep
                      bmREQ_HID_OUT,            //bmReqType
                      HID_REQUEST_SET_PROTOCOL, //bRequest
                      USB_HID_BOOT_PROTOCOL,    //wValLo
                      0x00,                     //wValHi
                      new_xinput->itf_num,      //wIndex
                      0x0000, 0x0000, NULL, NULL);
    }

    return new_xinput;
}

uint8_t XINPUT::free_xinput_device(usbh_xinput_t *xinput)
{
    uint8_t index;
    for (index = 0; index < XINPUT_MAXGAMEPADS; index++)
    {
        if (&xinput_devices[index] == xinput)
        {
            memset(xinput, 0, sizeof(usbh_xinput_t));
            USBH_XINPUT_DEBUG(F("USBH XINPUT: FREED XINPUT\n"));
            return 1;
        }
    }
    return 0;
}

usbh_xinput_t *usbh_xinput_get_device_list(void)
{
    return xinput_devices;
}

uint8_t usbh_xinput_is_chatpad_pressed(usbh_xinput_t *xinput, uint16_t code)
{
    if (xinput->bAddress == 0)
        return 0;

    if (code < 17 && (xinput->chatpad_state[0] & code))
        return 1;

    if (code < 17)
        return 0;

    if (xinput->chatpad_state[1] == code)
        return 1;

    if (xinput->chatpad_state[2] == code)
        return 1;

    return 0;
}

uint8_t usbh_xinput_was_chatpad_pressed(usbh_xinput_t *xinput, uint16_t code)
{
    //Button isnt pressed anymore, Clear it from the history
    if (usbh_xinput_is_chatpad_pressed(xinput, code) == 0)
    {
        for (uint8_t i = 0; i < 3; i++)
        {
            if (xinput->chatpad_state_old[i] == code)
                xinput->chatpad_state_old[i] = 0x00;
        }
        return 0;
    }

    //Button is pressed, and hasnt been pressed before
    if (xinput->chatpad_state_old[0] != code &&
        xinput->chatpad_state_old[1] != code &&
        xinput->chatpad_state_old[2] != code)
    {
        for (uint8_t i = 0; i < 3; i++)
        {
            if (xinput->chatpad_state_old[i] == 0)
            {
                xinput->chatpad_state_old[i] = code;
                return 1;
            }
        }
    }
    return 0;
}

uint8_t usbh_xinput_is_gamepad_pressed(usbh_xinput_t *xinput, uint16_t button_mask)
{
    if (xinput->bAddress == 0)
        return 0;

    return xinput->pad_state.wButtons & button_mask;
}

uint8_t usbh_xinput_was_gamepad_pressed(usbh_xinput_t *xinput, uint16_t button_mask)
{
    if (usbh_xinput_is_gamepad_pressed(xinput, button_mask))
    {
        if ((xinput->pad_state_wButtons_old & button_mask) == 0)
        {
            xinput->pad_state_wButtons_old |= button_mask;
            return 1;
        }
    }
    else
    {
        xinput->pad_state_wButtons_old &= ~button_mask;
    }
    return 0;
}

XINPUT::XINPUT(USB *p) : pUsb(p),
                         bAddress(0),
                         bIsReady(false),
                         PID(0), VID(0),
                         dev_num_eps(1)
{
    memset(xdata, 0x00, sizeof(xdata));
    if (pUsb)
    {
        pUsb->RegisterDeviceClass(this);
    }
}
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

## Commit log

2020-12-08 Remove wireless support and reduce getXYZ params for one controller only
2020-12-13 Replace UHS files with those from CMake branch
    [main.cpp]
2020-12-13 Remove commented out wireless line
2020-12-15 Add prototype rumble code for PS controllers
2020-12-16 Fix bug causing constant PS4 rumble
    [main.cpp]
2020-12-16 Correct OLED display size
    [main.cpp]
2021-01-08 Add voltage checking, reset on change, update OLED with voltage and cont type
    [main.cpp]
2021-01-08 Commit to switch dev machines
2021-01-15 Comment out voltage and other code
2021-01-21 PS4 motion working, reversed
    [main.cpp]
2021-01-23 Correctly invert PS3 right stick x axis motion input
    [main.cpp]
2021-01-23 Correct PS3 and PS4 cont motion orientation, ignore last commit
    [main.cpp]
2021-01-30 Completely replace getMotion function
    [main.cpp]
2021-02-05 Correct motion sensitivity display
    [main.cpp]
2021-02-05 Correct compile errors with rumble etc disabled
    [main.cpp]
2021-02-10 Remove unneeded ogx460 files
    [ogx360.brd, ogx360.sch]
2021-02-10 Add case files
    [Front cover.STL, Main Case.STL, Reset button base.STL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]
2021-02-17 Add PDP Xbox One wired controller
2022-03-31 update switchparser
2022-04-04 reconect ps4 switch bt
2022-04-05 actualizacion librerias xbox one s bt
    se actualizo compatibilidad con bt pa controles de xbox one, (no actualizados), xbox series aun no funcionan, se actualizo compatibilidad con analogos y botones para que se leyeran de manera correcta.
    [main.cpp]
2022-04-05 actualización libreria xbox bt
    no se habilita vibracion, de momento en xbox solo funciona con cable, control de xbox cableado en series s y x funciona completamente, para xbox one s, solo se conecta en bt en version anterior de fi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
